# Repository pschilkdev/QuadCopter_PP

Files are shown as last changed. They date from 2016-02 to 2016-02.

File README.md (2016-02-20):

# QuadCopter_PP<br>
Main Repository for all code, schematics and PCB board layouts for the Quadcopter Project.<br>
Personal Project 2015/16 IICS<br>
<br>
All code for various Pic Microcontrollers programmed in either XC8 or XC32. <br>
All schematics and PCB board layouts designed in KiCad. <br>
<br>
Naming Scheme for Code:<br>
&nbsp;PPQCU_{RC/QCU}_[Processor Name]<br>
<br>
<b>Key:</b><br>
&nbsp;PPQCU: <br>
&nbsp;&nbsp;Project Handle (<b>P</b>ersonal <b>P</b>roject <b>Q</b>uad<b>C</b>opter <b>C</b>ontrol <b>U</b>nit)<br>
&nbsp;RC / QCU:<br>
&nbsp;&nbsp;Location of the MicroController associated with the programm.<br>
&nbsp;&nbsp;&nbsp;RC: The MicroController is located on the Remote Control<br>
&nbsp;&nbsp;&nbsp;QCU: The MicroController is located on the Control Unit on the Quadcopter<br>
&nbsp;Processor Name:<br>
&nbsp;&nbsp;Name of the Processor<br>
<br>
<br>	
<b>Programs Included:</b><br>
&nbsp;PPQCU_CU_MAIN:<br>
&nbsp;&nbsp;MicroController:<br>
&nbsp;&nbsp;&nbsp;PIC32MX120F064H<br>
&nbsp;&nbsp;Language/Compiler:<br>
&nbsp;&nbsp;&nbsp;Programmed in C using the XC32 Complier.<br>
&nbsp;&nbsp;MicroController Purpose:<br>
&nbsp;&nbsp;&nbsp;Main processor on the Control Unit<br>
<br>
&nbsp;PPQCU_CU_BATSENSE:<br>
&nbsp;&nbsp;MicroController:<br>
&nbsp;&nbsp;&nbsp;PIC12F1840<br>
&nbsp;&nbsp;Language/Compiler:<br>
&nbsp;&nbsp;&nbsp;Programmed in C using the XC8 Complier<br>
&nbsp;&nbsp;MicroController Purpose:<br>
&nbsp;&nbsp;&nbsp;Battery Level Sensing, and low battery warning<br>
<br>
&nbsp;PPQCU_CU_INTERFACE:<br>
&nbsp;&nbsp;MicroController:<br>
&nbsp;&nbsp;&nbsp;PIC12F1840<br>
&nbsp;&nbsp;Language/Compiler:<br>
&nbsp;&nbsp;&nbsp;Programmed in C using the XC8 Complier<br>
&nbsp;&nbsp;MicroController Purpose:<br>
&nbsp;&nbsp;&nbsp;Interfacing to the ESC and, in turn, the motors.<br>
<br>
&nbsp;PPQCU_CU_LIGHTS:<br>
&nbsp;&nbsp;MicroController:<br>
&nbsp;&nbsp;&nbsp;PIC12F1840<br>
&nbsp;&nbsp;Language/Compiler:<br>
&nbsp;&nbsp;&nbsp;Programmed in C using the XC8 Complier<br>
&nbsp;&nbsp;Controller Purpose:<br>
&nbsp;&nbsp;&nbsp;UI on the QuadCopter<br>
<br>	
&nbsp;PPQCU_RC_REMOTE:<br>
&nbsp;&nbsp;MicroController:<br>
&nbsp;&nbsp;&nbsp;PIC18F26K22<br>
&nbsp;&nbsp;Language/Compiler:<br>
&nbsp;&nbsp;&nbsp;Programmed in C using the XC8 Complier<br>
&nbsp;&nbsp;MicroController Purpose:<br>
&nbsp;&nbsp;&nbsp;Main Processor on the Remote Controller<br>

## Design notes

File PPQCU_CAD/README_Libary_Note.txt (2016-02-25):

For all libaries please see:
https://github.com/pschilkdev/Kicad_libs

This Kicad Project uses following EESCHEMA Libaries:
	Debug.lib
	Logic.lib
	PIC.lib
	Regulator.lib
	Sensor.lib
	UI.lib

This Kicad Project uses following PCBNEW Libaries:
	General.pretty
	Passive.pretty
	Sensor.pretty
	UI.pretty

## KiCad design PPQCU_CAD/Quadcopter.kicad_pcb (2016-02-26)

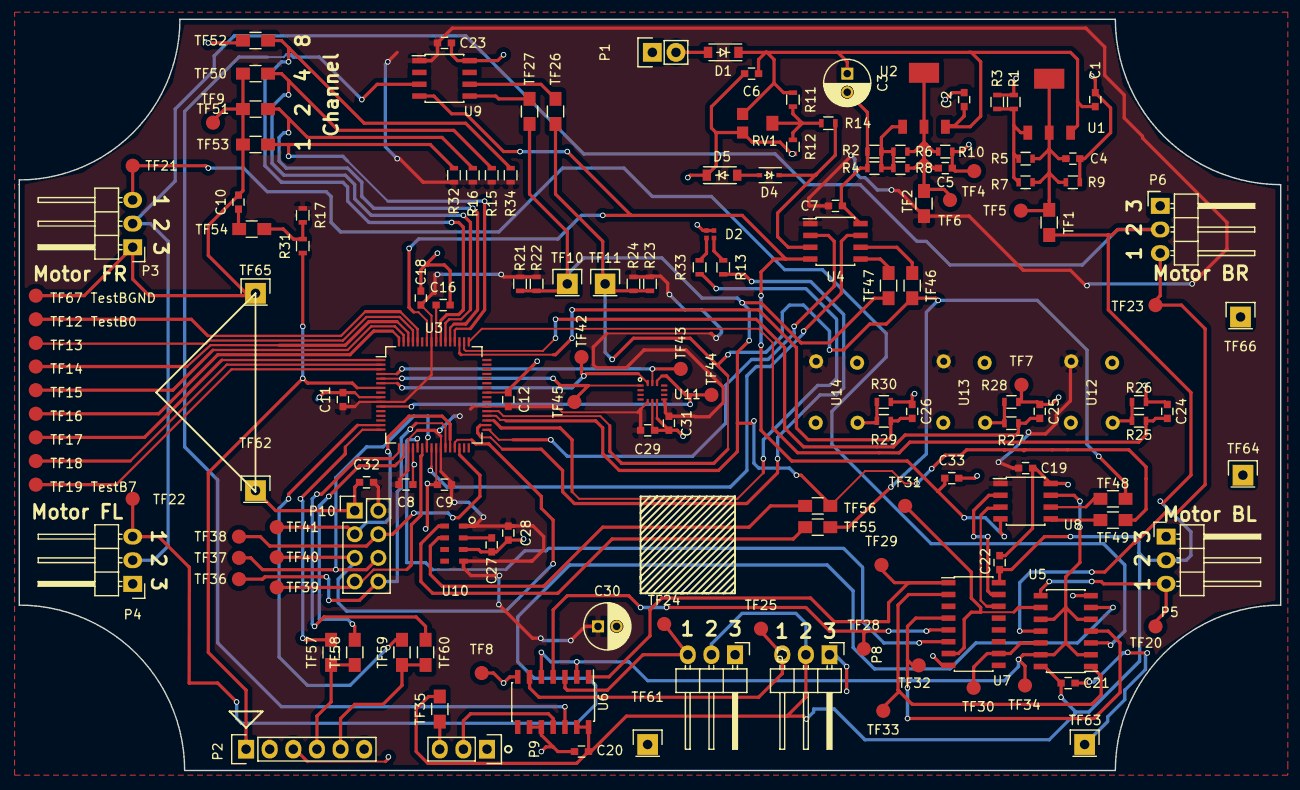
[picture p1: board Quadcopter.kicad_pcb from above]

Board: 2 copper layers, 135.6 x 80.8 mm, 155 parts (0 on the bottom side), 87 nets.

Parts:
C1, C2, C6, C7, C8, C9, C10, C11, C12, C18, C19, C20, C21, C22, C23, C27, C28, C29, C31, C32, C33: 0u1; C_0603
C3: 100uf; C_Radial_D5_L11_P2
C4, C5: 1uf; C_0603
C16, C24, C25, C26: 10u; C_0603
C30: 10u; C_Radial_D5_L11_P2
D1: D; SOD-123
D2: Dual_LED; dualLED
D4: 3.4V; SOD-323
D5: TV; SOD-123
P1: Battery; Pin_Header_Straight_1x02
P2: DEBUG; Pin_Header_Straight_1x06
P3: Serv1; Pin_Header_Angled_1x03
P4: Serv2; Pin_Header_Angled_1x03
P5: Serv3; Pin_Header_Angled_1x03
P6: Serv4; Pin_Header_Angled_1x03
P7: SecServ1; Pin_Header_Angled_1x03
P8: SecServ2; Pin_Header_Angled_1x03
P9: ws2812; Pin_Header_Straight_1x03
P10: CONN_02X04; Pin_Header_Straight_2x04
R1, R14, R31: 1K; R_0603
R2: 540R; R_0603
R3, R4, R7, R8, R11, R12, R22, R24: TV; R_0603
R5, R6: 330R; R_0603
R9: 680R; R_0603
R10: 470R; R_0603
R13, R33: 50R; R_0603
R15, R16, R17, R21, R23, R26, R28, R30, R32, R34: 10K; R_0603
R25, R27, R29: 100K; R_0603
RV1: 100K; EVM3Y
TF1: 5V; R_0805_HandSoldering
TF2: 3V; R_0805_HandSoldering
TF4, TF7, TF8, TF9: GND; Measurement_Point_Round-SMD-Pad_Small
TF5: 5V; Measurement_Point_Round-SMD-Pad_Small
TF6: 3V3; Measurement_Point_Round-SMD-Pad_Small
TF10: i2cDAT; Pin_Header_Straight_1x01
TF11: i2cCLK; Pin_Header_Straight_1x01
TF12: TestB0; Measurement_Point_Round-SMD-Pad_Small
TF13: TestB1; Measurement_Point_Round-SMD-Pad_Small
TF14: TestB2; Measurement_Point_Round-SMD-Pad_Small
TF15: TestB3; Measurement_Point_Round-SMD-Pad_Small
TF16: TestB4; Measurement_Point_Round-SMD-Pad_Small
TF17: TestB5; Measurement_Point_Round-SMD-Pad_Small
TF18: TestB6; Measurement_Point_Round-SMD-Pad_Small
TF19: TestB7; Measurement_Point_Round-SMD-Pad_Small
TF20: s3; Measurement_Point_Round-SMD-Pad_Small
TF21: s1; Measurement_Point_Round-SMD-Pad_Small
TF22: s2; Measurement_Point_Round-SMD-Pad_Small
TF23: s4; Measurement_Point_Round-SMD-Pad_Small
TF24: ss1; Measurement_Point_Round-SMD-Pad_Small
TF25: ss2; Measurement_Point_Round-SMD-Pad_Small
TF26, TF27: li; R_0805_HandSoldering
TF28: u6; Measurement_Point_Round-SMD-Pad_Small
TF29: u5; Measurement_Point_Round-SMD-Pad_Small
TF30: u4; Measurement_Point_Round-SMD-Pad_Small
TF31: u3; Measurement_Point_Round-SMD-Pad_Small
TF32: u2; Measurement_Point_Round-SMD-Pad_Small
TF33: u1; Measurement_Point_Round-SMD-Pad_Small
TF34: ga; Measurement_Point_Round-SMD-Pad_Small
TF35: L5; R_0805_HandSoldering
TF36: wIRQ; Measurement_Point_Round-SMD-Pad_Small
TF37: wMOSI; Measurement_Point_Round-SMD-Pad_Small
TF38: wCSN; Measurement_Point_Round-SMD-Pad_Small
TF39: wMISO; Measurement_Point_Round-SMD-Pad_Small
TF40: wSCK; Measurement_Point_Round-SMD-Pad_Small
TF41: wCE; Measurement_Point_Round-SMD-Pad_Small
TF42: aMOSI; Measurement_Point_Round-SMD-Pad_Small
TF43: aSCK; Measurement_Point_Round-SMD-Pad_Small
TF44: aCSB; Measurement_Point_Round-SMD-Pad_Small
TF45: MISO; Measurement_Point_Round-SMD-Pad_Small
TF46, TF47: bi; R_0805_HandSoldering
TF48, TF49: ii; R_0805_HandSoldering
TF50: a3; R_0805_HandSoldering
TF51: a2; R_0805_HandSoldering
TF52: a4; R_0805_HandSoldering
TF53: a1; R_0805_HandSoldering
TF54: cd; R_0805_HandSoldering
TF55, TF56: pi; R_0805_HandSoldering
TF57: d1; R_0805_HandSoldering
TF58: d2; R_0805_HandSoldering
TF59: c1; R_0805_HandSoldering
TF60: c2; R_0805_HandSoldering
TF61, TF62, TF63, TF64, TF65, TF66: GND; Pin_Header_Straight_1x01
TF67: TestBGND; Measurement_Point_Round-SMD-Pad_Small
U1, U2: LM317; SOT-233-4
U3: PIC32MX120F064H-I/PT; LQFP-64_10x10mm_Pitch0.5mm
U4, U8, U9: PIC12F1840; SOIC-8_3.9x4.9mm_Pitch1.27mm
U5, U6: 74HC08; SOIC-14_3.9x8.7mm_Pitch1.27mm
U7: 74HC4017; SOIC-16_3.9x9.9mm_Pitch1.27mm
U10: MPL3115A2
U11: BMI160
U12, U13, U14: BTN; B3F-1000

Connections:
+3V3: C7.2, C8.2, C9.1, C11.1, C12.1, C18.1, C19.2, C23.2, C28.1, C29.1, C30.1, C31.1, C32.2, P2.2, P10.2, R15.1, R16.1, R17.1, R21.1, R22.1, R23.1, R24.1, R32.1, R34.1, TF2.2, U3.10, U3.19, U3.26, U3.38, U3.57, U4.1, U8.1, U9.1, U10.1, U10.4, U11.5, U11.8, U12.3, U13.3, U14.3
+5V: C20.1, C21.1, C22.1, P3.2, P4.2, P5.2, P6.2, P7.2, P8.2, TF1.2, TF35.2, U5.14, U6.13, U6.14, U7.16
+BATT: C1.1, C2.1, C3.1, C6.1, D1.1, R11.1, RV1.1, U1.3, U2.3
BTN1: C24.1, R25.2, U3.49
BTN2: C25.1, R27.2, U3.50
BTN3: C26.1, R29.2, U3.51
GND: C1.2, C2.2, C3.2, C4.2, C5.2, C6.2, C7.1, C8.1, C9.2, C10.2, C11.2, C12.2, C16.2, C18.2, C19.1, C20.2, C21.2, C22.2, C23.1, C24.2, C25.2, C26.2, C27.2, C28.2, C29.2, C30.2, C31.2, C32.1, C33.2, D2.3, D2.4, D5.1, P1.1, P2.3, P3.1, P4.1, P5.1, P6.1, P7.1, P8.1, P9.1, P10.1, R1.2, R2.2, R3.2, R4.2, R9.2, R10.2, R12.2, R26.2, R28.2, R30.2, RV1.3, TF4.1, TF7.1, TF8.1, TF9.1, TF50.1, TF51.1, TF52.1, TF53.1, TF61.1, TF62.1, TF63.1, TF64.1, TF65.1, TF66.1, TF67.1, U3.9, U3.20, U3.25, U3.41, U4.8, U5.7, U6.7, U6.9, U6.10, U7.8, U8.8, U9.8, U10.3, U11.6, U11.7
MCLR: P2.1, R31.1, U3.7
unnamed: C4.1, R5.1, R7.1, R9.1, TF1.1, TF5.1, U1.2, U1.4
unnamed: C5.1, R6.1, R8.1, R10.1, TF2.1, TF6.1, U2.2, U2.4
unnamed: C10.1, TF54.2
unnamed: C16.1, U3.56
unnamed: C27.1, U10.2
unnamed: D1.2, P1.2
unnamed: D2.1, R33.1
unnamed: D2.2, R13.1
unnamed: D4.1, R14.1, U4.3
unnamed: D4.2, D5.2
unnamed: P2.4, TF57.1, TF58.1
unnamed: P2.5, TF59.1, TF60.1
unnamed: P3.3, TF21.1, U5.3
unnamed: P4.3, TF22.1, U5.6
unnamed: P5.3, TF20.1, U5.8
unnamed: P6.3, TF23.1, U5.11
unnamed: P7.3, TF24.1, U6.3
unnamed: P8.3, TF25.1, U6.6
unnamed: P9.3, TF35.1
unnamed: R1.1, R3.1, R5.2, R7.2, U1.1
unnamed: R2.1, R4.1, R6.2, R8.2, U2.1
unnamed: R11.2, R12.1, R14.2, RV1.2
unnamed: R15.2, TF50.2, U3.54
unnamed: R16.2, TF51.2, U3.53
unnamed: R17.2, R31.2, TF54.1
unnamed: R25.1, R26.1, U12.1
unnamed: R27.1, R28.1, U13.1
unnamed: R29.1, R30.1, U14.1
unnamed: R32.2, TF53.2, U3.52
unnamed: R34.2, TF52.2, U3.55
unnamed: TF26.1, U9.6
unnamed: TF27.1, U9.5
unnamed: TF28.1, U6.4, U7.5
unnamed: TF29.1, U6.1, U7.1
unnamed: TF30.1, U5.12, U7.10
unnamed: TF31.1, U5.9, U7.7
unnamed: TF32.1, U5.4, U7.4
unnamed: TF33.1, U5.1, U7.2
unnamed: TF34.1, U5.2, U5.5, U5.10, U5.13, U6.2, U6.5, U8.7
unnamed: TF46.2, U4.6
unnamed: TF47.2, U4.5
unnamed: TF48.2, U8.6
unnamed: TF49.2, U8.5
unnamed: TF55.1, U10.8
unnamed: TF56.1, U10.7
unnamed: U7.14, U8.3
unnamed: U7.15, U8.2
ProgC_1: TF59.2, U3.15
ProgC_2: TF60.2, U3.17
ProgD_1: TF57.2, U3.16
ProgD_2: TF58.2, U3.18
SCLR: C33.1, U3.58, U4.4, U8.4, U9.4
ServIntRD: U3.21, U7.6
T0: TF12.1, U3.60
T1: TF13.1, U3.61
T2: TF14.1, U3.62
T3: TF15.1, U3.63
T4: TF16.1, U3.64
T5: TF17.1, U3.1
T6: TF18.1, U3.2
T7: TF19.1, U3.3
WS_out: P9.2, U6.11
WS_sig: U6.12, U9.3
aCSB: TF44.1, U3.11, U11.12
aMISO: TF45.1, U3.5, U11.1
aMOSI: TF42.1, U3.6, U11.14
aSCK: TF43.1, U3.4, U11.13
batled_in: U3.33, U4.2
batled_out1: R13.2, U3.34
batled_out2: R33.2, U3.35
battWarn: U3.24, U4.7
i2cCLK: R23.2, R24.2, TF11.1, TF26.2, TF46.1, TF48.1, TF55.2, U3.37
i2cDAT: R21.2, R22.2, TF10.1, TF27.2, TF47.1, TF49.1, TF56.2, U3.36
wCE: P10.3, TF41.1, U3.28
wCSN: P10.4, TF38.1, U3.30
wIRQ: P10.8, TF36.1, U3.27
wMISO: P10.7, TF39.1, U3.22
wMOSI: P10.6, TF37.1, U3.23
wSCK: P10.5, TF40.1, U3.29

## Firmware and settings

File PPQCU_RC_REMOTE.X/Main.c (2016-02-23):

/* 
 * File:   Main.c
 * Author: Philipp
 *
 * Created on January 2, 2016, 3:40 AM
 */

#include <stdio.h>
#include <stdlib.h>
#include "config.h"

void init_ADC();
void init_OSC();
void init_IO();
double map(double value, float x_min, float x_max, float y_min, float y_max);
void calibrate_joystick();
int sample(char);
int read_ADC(char channel);
void save_calib();
void load_calib();
int ee_read(char ad);
void ee_write(char ad, int val);

#define button PORTCbits.RC1
#define led LATAbits.LA5
#define deadzone 15
#define timeout 5000

#define ac_j1 0b00000
#define ac_j2 0b00001
#define ac_j3 0b00010
#define ac_j4 0b00011

int sample1;
int sample2;
int sample3;
int sample4;

char v1;
char v2;
char v3;
char v4;

#define ad_j1_min 0x01
#define ad_j1_max 0x03

#define ad_j2_min 0x05
#define ad_j2_max 0x07
#define ad_j2_center 0x09

#define ad_j3_min 0x0B
#define ad_j3_max 0x0D
#define ad_j3_center 0x0F

#define ad_j4_min 0x11
#define ad_j4_max 0x13
#define ad_j4_center 0x15

int j1_min;
int j1_max;

int j2_min;
int j2_max;
int j2_center;

int j3_min;
int j3_max;
int j3_center;

int j4_min;
int j4_max;
int j4_center;

int main(int argc, char** argv) {
    init_IO();
    init_OSC();
    init_ADC();

    if (button) {
        calibrate_joystick();
        save_calib();
    } else {
        load_calib();
    }

    while (1) {
        //Read ADC
        //lx
        sample1 = read_ADC(ac_j1);

        //ly
        sample2 = read_ADC(ac_j2);

        //rx
        sample3 = read_ADC(ac_j3);

        //ry 
        sample4 = read_ADC(ac_j4);

        //add center deadzone to 2 3 and 4, map to 8 bit
        if (sample2 <= (j2_center + deadzone) && sample2 >= (j2_center - deadzone)) {
            v2 = 127;
        } else {
            if (sample2 > (j2_max - 10))
                sample2 = (j2_max - 10);
            if (sample2 < j2_min)
                sample2 = j2_min;

            if (sample2 > j2_center) {
                v2 = (char) map(sample2, j2_center, j2_max - 10, 128, 255);
            } else {
                v2 = (char) map(sample2, j2_min, j2_center, 0, 128);
            }
        }

        if (sample3 <= (j3_center + deadzone) && sample3 >= (j3_center - deadzone)) {
            v3 = 128;
        } else {
            if (sample3 > (j3_max - 10))
                sample3 = (j3_max - 10);
            if (sample3 < j3_min)
                sample3 = j3_min;
            if (sample3 > j3_center) {
                v3 = (char) map(sample3, j3_center, j3_max - 10, 128, 255);
            } else {
                v3 = (char) map(sample3, j3_min, j3_center, 0, 128);
            }
        }

        if (sample4 <= (j4_center + deadzone) && sample4 >= (j4_center - deadzone)) {
            v4 = 128;
        } else {
            if (sample4 > (j4_max - 10))
                sample4 = (j4_max - 10);
            if (sample4 < j4_min)
                sample4 = j4_min;
            if (sample4 > j4_center) {
                v4 = (char) map(sample4, j4_center, j4_max - 10, 128, 255);
            } else {
                v4 = (char) map(sample4, j4_min, j4_center, 0, 128);
            }
        }

        //add bottom deadzone to 1, map to 8 bit
        if (sample1 >= (j1_max - deadzone))
            v1 = 255;
        else
            v1 = (char) map(sample1, j1_min, j1_max - deadzone, 0, 255);
        asm("NOP");

        //invert left joystick:
        v1 = 255 - v1;
        v2 = 255 - v2;

        //Send
        char out[5];
        out[0] = 0;
        out[1] = v1;
        out[2] = v2;
        out[3] = v3;
        out[4] = v4;
    }
}

void init_ADC() {
    ADCON1bits.PVCFG = 0b00;
    ADCON1bits.NVCFG = 0b00;
    ADCON2bits.ADFM = 0b1;
    ADCON2bits.ACQT = 0b100;
    ADCON2bits.ADCS = 0b101;
    ADCON0bits.ADON = 1;
}

void init_OSC() {
    OSCCONbits.IRCF = 0b111;
    OSCTUNEbits.PLLEN = 0;
}

void init_IO() {
    //Joystick In:
    ANSELA = 0;
    ANSELB = 0;
    ANSELC = 0;
    ANSELAbits.ANSA0 = 1;
    TRISAbits.TRISA0 = 1;
    ANSELAbits.ANSA1 = 1;
    TRISAbits.TRISA1 = 1;
    ANSELAbits.ANSA2 = 1;
    TRISAbits.TRISA2 = 1;
    ANSELAbits.ANSA3 = 1;
    TRISAbits.TRISA3 = 1;

    //Button in:
    TRISCbits.RC1 = 1;

    //LED Out
    TRISAbits.RA5 = 0;

    //NRF:
    //SCK
    TRISCbits.RC3 = 0;
    //MISO
    TRISCbits.RC4 = 1;
    //MOSI
    TRISCbits.RC5 = 0;
    //CE
    TRISCbits.RC0 = 0;
    //CSN
    TRISCbits.RC7 = 0;
    //IRQ
    TRISCbits.RC6 = 1;
}

void calibrate_joystick() {
    asm("nop");
    led = 1;
    for (int a = 0; a < 10; a++)
        for (int b = 0; b < 20000; b++) {
        }
    led = 0;
    j2_center = read_ADC(ac_j2);
    j3_center = read_ADC(ac_j3);
    j4_center = read_ADC(ac_j4);

    //samples
    j1_min = sample(ac_j1);
    j2_min = sample(ac_j2);
    j1_max = sample(ac_j1);
    j2_max = sample(ac_j2);

    j3_max = sample(ac_j3);
    j4_max = sample(ac_j4);
    j3_min = sample(ac_j3);
    j4_min = sample(ac_j4);

    led = 0;
    for (int a = 0; a < 10; a++)
        for (int b = 0; b < 20000; b++) {
        }
    led = 1;
    for (int a = 0; a < 10; a++)
        for (int b = 0; b < 20000; b++) {
        }
    led = 0;
    for (int a = 0; a < 10; a++)
        for (int b = 0; b < 20000; b++) {
        }
    led = 1;
    for (int a = 0; a < 10; a++)
        for (int b = 0; b < 20000; b++) {
        }
    led = 0;
}

double map(double value, float x_min, float x_max, float y_min, float y_max) {
    return (y_min + (((y_max - y_min) / (x_max - x_min)) * (value - x_min)));
}

int sample(char channel) {
    led = 0;
    //wait for press
    while (button) {
    }
    //wait for release
    while (!button) {
    }
    //read
    int result = read_ADC(channel);
    //timeout    
    led = 1;
    for (int a = 0; a < 20; a++)
        for (int b = 0; b < 20000; b++) {
        }
    led = 0;
    return result;
}

int read_ADC(char channel) {
    ADCON0bits.CHS = channel;
    ADCON0bits.GO_nDONE = 1;
    while (ADCON0bits.GO_nDONE) {
        ;
    }
    return ((ADRESH & 0b11) << 8) | ADRESL;
}

void save_calib() {
    ee_write(ad_j1_min, j1_min);
    ee_write(ad_j1_max, j1_max);

    ee_write(ad_j2_min, j2_min);
    ee_write(ad_j2_max, j2_max);
    ee_write(ad_j2_center, j2_center);

    ee_write(ad_j3_min, j3_min);
    ee_write(ad_j3_max, j3_max);
    ee_write(ad_j3_center, j3_center);

    ee_write(ad_j4_min, j4_min);
    ee_write(ad_j4_max, j4_max);
    ee_write(ad_j4_center, j4_center);
}

void load_calib() {
    j1_min = ee_read(ad_j1_min);
    j1_max = ee_read(ad_j1_max);
    
    j2_min = ee_read(ad_j2_min);
    j2_max = ee_read(ad_j2_max);
    j2_center = ee_read(ad_j2_center);
    
    j3_min = ee_read(ad_j3_min);
    j3_max = ee_read(ad_j3_max);
    j3_center = ee_read(ad_j3_center);
    
    j4_min = ee_read(ad_j4_min);
    j4_max = ee_read(ad_j4_max);
    j4_center = ee_read(ad_j4_center);
}

int ee_read(char ad) {
    EECON1bits.EEPGD = 0;
    EECON1bits.CFGS = 0;
    EEADR = ad;
    EECON1bits.RD = 1;
    char val1 = EEDATA;
    
    EECON1bits.EEPGD = 0;
    EECON1bits.CFGS = 0;
    EEADR = ad + 1;
    EECON1bits.RD = 1;
    char val2 = EEDATA;
    
    int result = (0b11 & val1)|val2;
    return result;
}

void ee_write(char ad, int val) {
    char w1 = (val & 0b1100000000) >> 8;
    char w2 = val & 0b111111111;
    
    EECON1bits.EEPGD = 0;
    EECON1bits.CFGS = 0;
    EECON1bits.WREN = 1;
    EEADR = ad;
    EEDATA = w1;
    EECON2 = 0x55;
    EECON2 = 0xAA;
    EECON1bits.WR = 1;
    while(EECON1bits.WR){;}
    
    EECON1bits.EEPGD = 0;
    EECON1bits.CFGS = 0;
    EECON1bits.WREN = 1;
    EEADR = ad+1;
    EEDATA = w2;
    EECON2 = 0x55;
    EECON2 = 0xAA;
    EECON1bits.WR = 1;
    while(EECON1bits.WR){;}
}

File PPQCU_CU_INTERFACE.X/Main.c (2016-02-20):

/* 
 * File:   Main.c
 * Author: Philipp
 *
 * Created on December 29, 2015, 11:35 PM
 */

#include <stdio.h>
#include <stdlib.h>
#include "config.h"


//INIT
void init_OSC();
void init_INT();
void init_I2C();
void init_IO();

#define MUX_RESET LATAbits.LATA5
#define MUX_ADVANCE LATAbits.LATA4
#define GATE LATAbits.LATA0

#define IIC_ADR_INT 0x30
//OPERATION
void handshake();
void output(int value);
void reset_mux();
void timeout();
void receive();


//Servo Values (0 - 2^12)
int Serv1;
int Serv2;
int Serv3;
int Serv4;
int Serv5;
int Serv6;


int rc1, rc2, rc3, rc4, rc5, rc6;
int error;
int count;

int currentVal;
char currentValH;
char currentValL;



/*
 *  
 */
int i;

int main(int argc, char** argv) {

    for (int xz = 0; xz < 10000; xz++) {
        asm("NOP");
    }

    Serv1 = 0;
    Serv2 = 0;
    Serv3 = 0;
    Serv4 = 0;
    Serv5 = 0;
    Serv6 = 0;

    init_IO();
    init_OSC();
    init_INT();
    init_I2C();

    handshake();
    while (1) {
        output(Serv1);
        output(Serv2);
        output(Serv3);
        output(Serv4);
        output(Serv5);
        output(Serv6);

        while (1) {
            if (PIR1bits.SSP1IF) {
                error = 0;
                //RECEIVE
                PIR1bits.SSP1IF = 0;
                //clear Buffer Full Flag
                int temp = SSP1BUF;
                receive();
                //Reconstruct Data
                if (!error) {
                    Serv1 = (0b111111111111) & ((rc1 << 4) | ((rc2 & 0b11110000) >> 4));
                    Serv2 = (0b111111111111) & (((rc2 & 0b1111) << 8) | rc3);
                    Serv3 = (0b111111111111) & ((rc4 << 4) | ((rc5 & 0b11110000) >> 4));
                    Serv2 = (0b111111111111) & (((rc5 & 0b1111) << 8) | rc6);
                }
                PIR1bits.SSP1IF = 0;
                return;
                reset_mux();
            }
        }

    }
    return (EXIT_SUCCESS);
}

void init_OSC() {

    //Clock Frequency 8mhz
    OSCCONbits.IRCF = 0b1110;
    //Multiply clock by 4 to yield 32
    OSCCONbits.SPLLEN = 0b1;
    //Clock determined by oscillator config fuses
    OSCCONbits.SCS = 0b00;
}

void init_INT() {
    //Reset all Flags and disable all interrupts
    INTCONbits.TMR0IF = 0b0;
    INTCONbits.INTF = 0b0;
    INTCONbits.IOCIF = 0b0;
    PIE1 = 0b0;
    PIE2 = 0b0;
    PIR1 = 0b0;
    PIR1 = 0b0;

    //Timer0(Equivelant)
    OPTION_REGbits.TMR0CS = 0b0;
    OPTION_REGbits.PSA = 0b0;
    OPTION_REGbits.PS = 0b101;

    //Timer1(value)
    T1CONbits.TMR1CS = 0b00;
    T1CONbits.T1CKPS = 0b00;
    T1CONbits.T1OSCEN = 0b0;
    T1CONbits.TMR1ON = 0b0;

    //Timer2(timeout)
    T2CONbits.T2OUTPS = 0b0110;
    T2CONbits.T2CKPS = 0b11;
    T2CONbits.TMR2ON = 1;
}

void init_I2C() {
    SSP1CON1bits.SSPEN = 0;
    SSP1CON1bits.SSPM = 0b0110;
    SSP1STATbits.SMP = 0;
    SSP1ADD = 0x30;
    SSP1CON2bits.SEN = 0;
    PIR1bits.SSP1IF = 0;
    SSP1CON1bits.SSPEN = 1;
}

void init_IO() {
    ANSELA = 0b0;
    TRISAbits.TRISA0 = 0;
    TRISAbits.TRISA4 = 0;
    TRISAbits.TRISA5 = 0;
}

void handshake() {
    //TODO
}

void output(int value) {
    //turn into 13 bit value
    value = value << 1;

    //Config Timers
    //TM1: Val Timer
    PIR1bits.TMR1IF = 0;
    T1CONbits.TMR1ON = 0;
    currentVal = (((TM_VAL_PRELOAD_H << 8) | TM_VAL_PRELOAD_L) + (8185 - value));
    currentValH = (currentVal & 0xFF00) >> 8;
    currentValL = currentVal & 0x00FF;

    //Advance MUX
    MUX_ADVANCE = 1;
    for (int i = 0; i < 50; i++) {
        asm("nop");
    }
    MUX_ADVANCE = 0;

    //===Time Sensitive===
    //Start Equivelant wait (2.1 ms)
    INTCONbits.TMR0IF = 0;
    TMR0 = TM_EQV_PRELOAD;


    //1ms default wait
    INTCONbits.TMR0IF = 0;
    TMR1H = TM_VAL_PRELOAD_H;
    TMR1L = TM_VAL_PRELOAD_L;
    T1CONbits.TMR1ON = 0b1;

    //Open Gate
    GATE = 1;


    //wait for finish
    while (!PIR1bits.TMR1IF) {
    }
    T1CONbits.TMR1ON = 0;
    PIR1bits.TMR1IF = 0;


    //Start valued
    TMR1H = currentValH;
    TMR1L = currentValL;
    T1CONbits.TMR1ON = 1;

    //wait for finish
    while (!PIR1bits.TMR1IF) {
        asm("nop");
    }

    //Close Gate
    GATE = 0b0;

    //Reset T1

    T1CONbits.TMR1ON = 0;
    PIR1bits.TMR1IF = 0;

    //Wait till equivelant is over
    while (!INTCONbits.TMR0IF) {
        asm("nop");
    }
    INTCONbits.TMR0IF = 0;

}

void reset_mux() {
    MUX_RESET = 1;
    for (int i = 0; i < 50; i++) {
        asm("nop");
    }
    MUX_RESET = 0;
}

void wait(int time) {
    int n = 0;
    while (!PIR1bits.SSP1IF) {
        n++;
        if (n > time) {
            error = 1;
            return;
        }
    }
}

void receive() {
    wait(1000);
    if (error)
        return;
    rc1 = SSP1BUF;

    wait(1000);
    if (error)
        return;
    rc2 = SSP1BUF;

    wait(1000);
    if (error)
        return;
    rc3 = SSP1BUF;

    wait(1000);
    if (error)
        return;
    rc4 = SSP1BUF;

    wait(1000);
    if (error)
        return;
    rc5 = SSP1BUF;

    wait(1000);
    if (error)
        return;
    rc6 = SSP1BUF;
}

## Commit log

2015-12-31 Started work on SPI. INIT completed but untested
2015-12-31 Oscillator Setup for Interface Chip
    [Main.c]
2015-12-31 Added missing handshake function
    [Main.c]
2015-12-31 Fixed another missing method
    [Main.c]
2016-01-02 Added first draft of servo interfacing. Untested
2016-01-02 Setup general programm structure and flow for BatSense
2016-01-02 Added ADC code. Untested
2016-01-02 Fixed general programm structure
    [Main.c]
2016-01-02 Finished SPI interface. Untested
2016-01-04 Finished I2C interpret and bit stepthrough for LIGHTS
2016-01-22 Tested SPI Bus, Basic function present. Updated Gitignore for test-projects
2016-01-26 SPI BUS WORKING
2016-01-26 Fixed issue with SPI read: Wait for buffer to be written to be SPIxBUF
    [SPI.c]
2016-01-28 Updated init_IO for NRF and test code for NRF SPI
2016-01-28 Started work on BMI SPI interface, UNTESTED
2016-01-30 Fixed Complier errors with BMI read_multiple
    [BMI.c]
2016-02-04 Fixed SPI channel selection
    [NRF.c]
2016-02-08 Started work on I2C interface
2016-02-10 Finished I2C Config Register Headers
2016-02-11 Fixed I2C Adress
2016-02-11 Added missing ack function and finished receive and transmit routine. Untested
    [IIC.c]
2016-02-13 Fixed small error in IIC status routine
    [IIC.c]
2016-02-13 Started work on I2C Quadcopter Protocol
2016-02-13 Continued work on first draft of Quadcopter I2C Protocol
2016-02-14 Fixed timeout. Interface code is now fully tested. Drafted I2C interface, untested
    [Main.c]
2016-02-20 Updated gitignore for KiCad
2016-02-20 Intital commit of board and schematic. Rev. 1. Sent to Fab
    [Quadcopter.kicad_pcb, Quadcopter.sch]
2016-02-20 Removed Servo Interface Ready, as it would cause a 5V signal on the pic32mx120
    [Quadcopter.sch]
2016-02-20 Tied Inverted advance of Johnson Counter to ground, as floating input causes bad output signals
    [Quadcopter.sch]
2016-02-20 Fixed motor I2C interface
    [Main.c]
2016-02-21 Worked on battery level recorvery setup
2016-02-21 Fixed Battery Level Warn Signals to main Processor
    [Quadcopter.sch]
2016-02-21 Fixed small typing error
    [Quadcopter.sch]
2016-02-21 Fixed/Cleaned up IO handling
    [IO.h, Main.c]
2016-02-22 SAving remote calibration to eeprom now, untested
2016-02-23 fixed funciton prototypes
2016-02-24 Added note about broken header file
    [IO.h, Main.c]
2016-02-25 Upadted libary handling for KiCad, Saving lbaries for parts and footprints in seperate repo now
    [Quadcopter.kicad_pcb]
2016-02-26 Fixed spelling error
    [Quadcopter.kicad_pcb]
2016-02-26 Fixed small overlaps/visual errors in layout
    [Quadcopter.kicad_pcb]
2016-02-28 Changed the way IIC transmits are polled. Now a failure to acknoledge by the slave will not cause the system to get stuck
    [IIC.c]
